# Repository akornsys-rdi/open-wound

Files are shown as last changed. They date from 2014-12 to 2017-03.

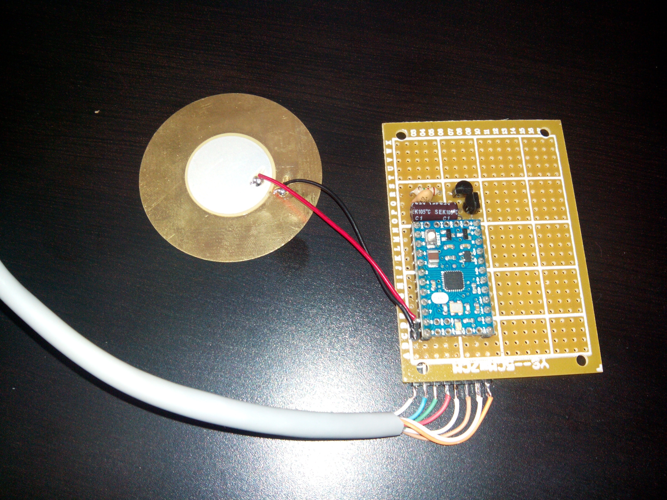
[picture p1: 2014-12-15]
img/photo001-slave-rc1.jpg

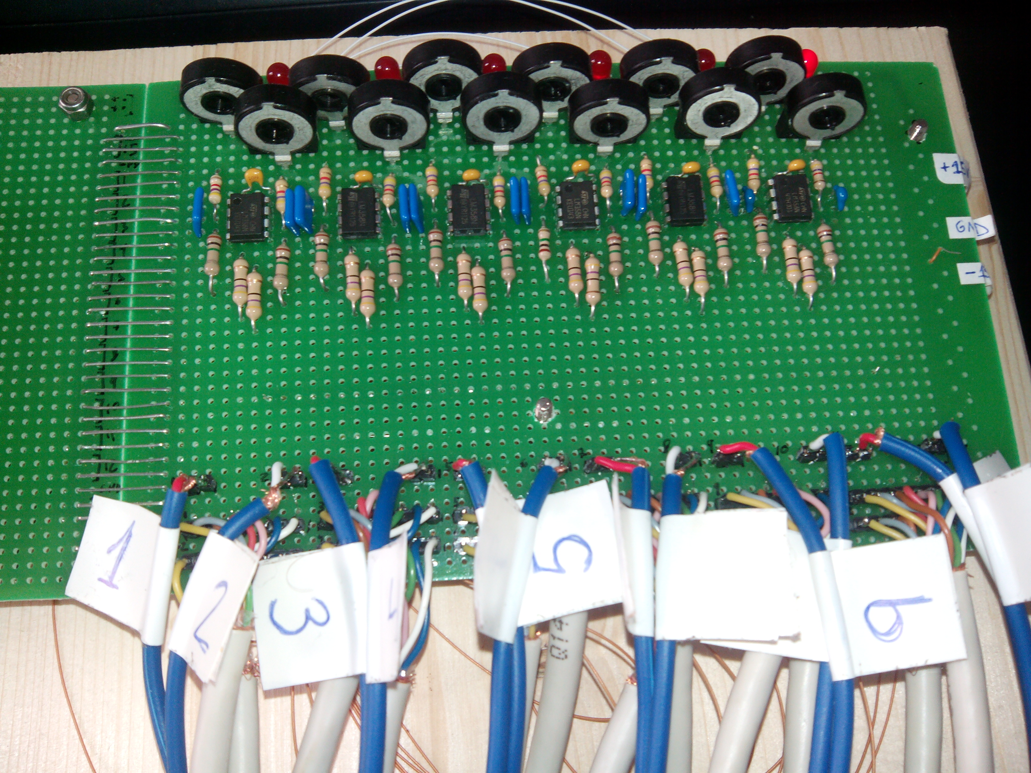
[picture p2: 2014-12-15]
img/photo003-master-rc1.jpg

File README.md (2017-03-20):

# open-wound #

                                                      _ 
         ___ _ __  ___ _ _   __ __ _____ _  _ _ _  __| |
        / _ \ '_ \/ -_) ' \  \ V  V / _ \ || | ' \/ _` |
        \___/ .__/\___|_||_|  \_/\_/\___/\_,_|_||_\__,_|
            |_|                                         

open wound, the system behind the [CUT artwork](http://arturomoyavillen.com/cut).

## ChangeLog  ##

-   Cambios generales:  
    *   Ahora open wound está bajo licencia GPLv3.  
    *   Open wound usa [versionamiento semántico](http://semver.org).  
-   Esclavos version 1.0.0:  
    *   Cambios menores en PCB.  
    *   El microcontrolador pasa a ser parte de la placa, no un módulo Arduino.  
    *   Los pines sin usar son salidas a nivel bajo no conectadas en lugar de entradas a masa.  
    *   Se añade un conector AVRISP de seis pines.  
    *   Se añade un conector de debug.  
    *   Placa diseñada en SMT..  
    *   Mejorado el método de conexión a la plancha sensora.  
    *   Ahora se usan conectores subminiatura con enclavamiento para su conexión.  
-   Maestro en versión 1.0.0-alpha:  
    *   El maestro ahora dispone de catorce canales para esclavos.  
    *   Se permiten cuatro canales para PIR compatibles con los esclavos.  
    *   Cambiado el CI amplificador.  
    *   Entrada de audio compacta medianteconector DA15F.  
    *   Buffer digital trigger-schmitt para acondicionar la señar de los esclavos.  
    *   Usa los propios LED del RJ45 para indicar conexión y dato entrante.  
    *   Ahora usa [FreeCanvas](https://github.com/synusia/freecanvas).

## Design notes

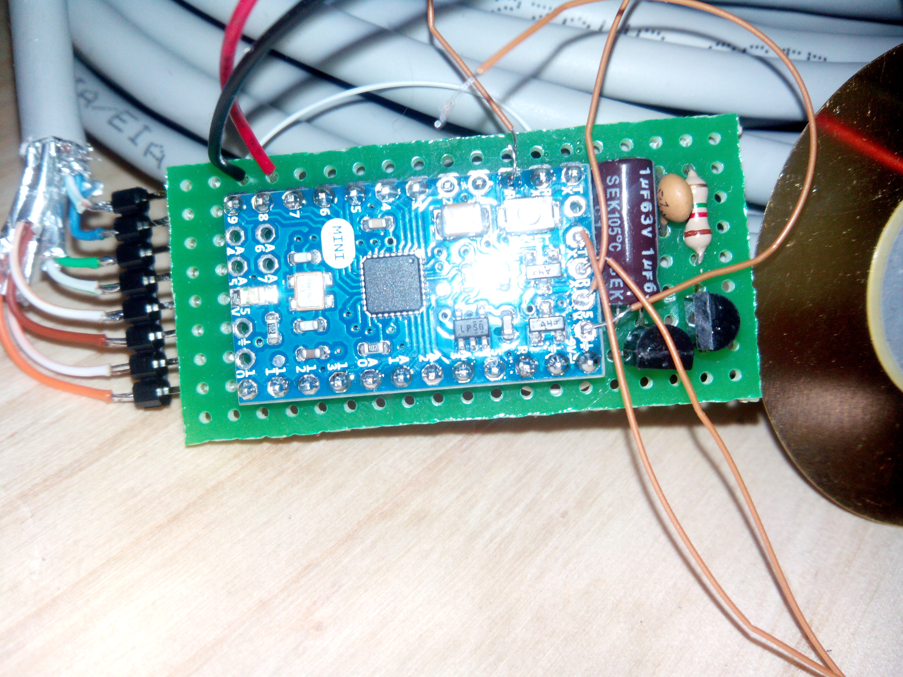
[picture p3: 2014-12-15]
img/photo004-slave-rc1.jpg

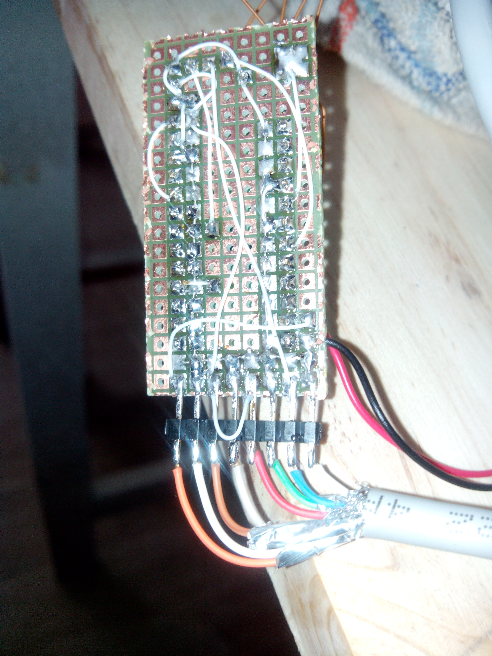
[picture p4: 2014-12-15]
img/photo005-slave-rc1.jpg

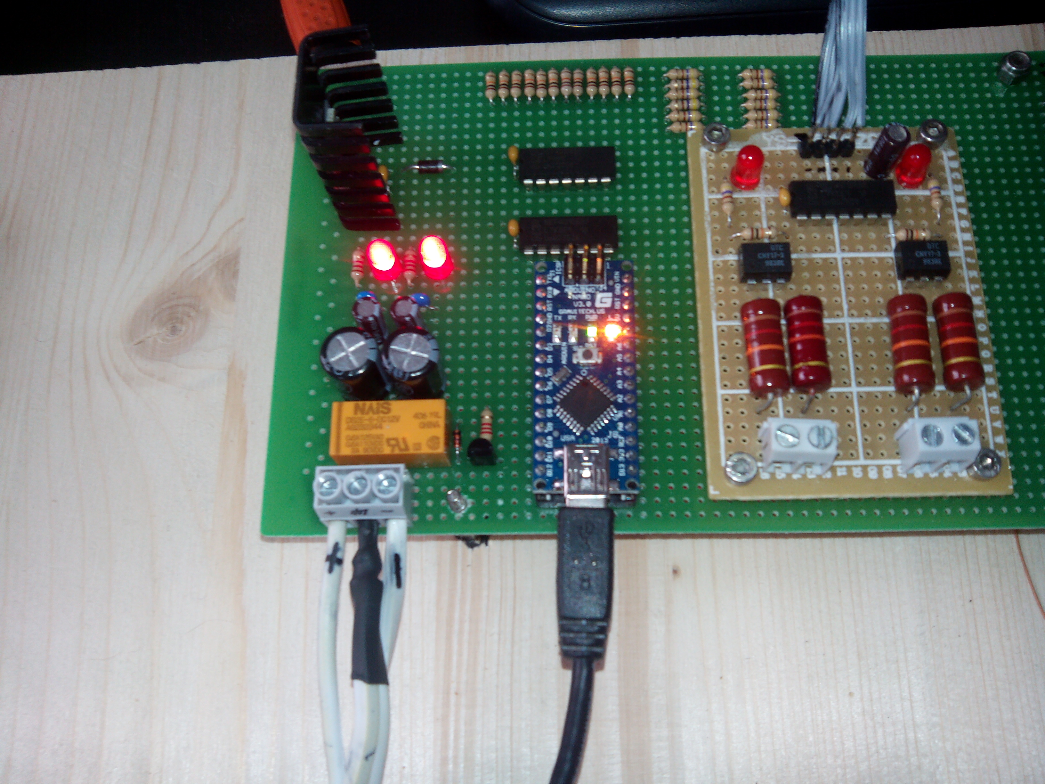
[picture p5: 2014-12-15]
img/photo002-master-rc1.jpg

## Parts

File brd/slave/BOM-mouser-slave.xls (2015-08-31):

open-wound:slave
Mouser REF | Fabr. N.º | Fabricante | Desc. | RoHS | Ciclo de vida | N.º Ref. del cliente | Ctd. pedido | Precio (EUR) | Ext.: (EUR)
598-AVE105M50B12T-F | AVE105M50B12T-F | Cornell Dubilier | Capacitadores electrolíticos de aluminio - SMD 1uF 50V 85C | Cumple RoHS |  |  | 1 | 0,314 € | 0,31 €
656-IL-Z-C3-A-15000 | IL-Z-C3-A-15000 | JAE Electronics | Alojamientos de cables y cabecera Socket Contact Crimp Tin 28-30AWG | Cumple RoHS |  |  | 16 | 0,053 € | 0,85 €
656-IL-Z-8S-S125C3 | IL-Z-8S-S125C3 | JAE Electronics | Alojamientos de cables y cabecera 8P Socket Housing 1.25mm Crimp | Cumple RoHS |  |  | 1 | 0,201 € | 0,20 €
656-IL-Z-6S-S125C3 | IL-Z-6S-S125C3 | JAE Electronics | Alojamientos de cables y cabecera 6P Socket Housing 1.25mm Crimp | Cumple RoHS |  |  | 1 | 0,146 € | 0,15 €
656-IL-Z-2S-S125C3 | IL-Z-2S-S125C3 | JAE Electronics | Alojamientos de cables y cabecera 2P Socket Housing 1.25mm Crimp | Cumple RoHS |  |  | 1 | 0,146 € | 0,15 €
656-IL-Z-8PL-SMTYE | IL-Z-8PL-SMTYE | JAE Electronics | Alojamientos de cables y cabecera 8P Pin Header 1.25mm R/A SMT | Cumple RoHS |  |  | 1 | 0,64 € | 0,64 €
656-IL-Z-6PL-SMTYE | IL-Z-6PL-SMTYE | JAE Electronics | Alojamientos de cables y cabecera 6P Pin Header 1.25mm R/A SMT | Cumple RoHS |  |  | 1 | 0,585 € | 0,59 €
656-IL-Z-2PL-SMTYE | IL-Z-2PL-SMTYE | JAE Electronics | Alojamientos de cables y cabecera 2P Pin Header 1.25mm R/A SMT | Cumple RoHS |  |  | 1 | 0,439 € | 0,44 €
71-CRCW0805-1.0M-E3 | CRCW08051M00FKEA | Vishay | Resistores de pel&iacute;cula gruesa - SMD 1/8watt 1Mohms 1% 100ppm | Conforme con RoHS por exención |  |  | 1 | 0,091 € | 0,09 €
603-SR0805JR-0710KL | SR0805JR-0710KL | Yageo | Resistores de pel&iacute;cula gruesa - SMD 10K ohm 5% 1/8W | Conforme con RoHS por exención |  |  | 1 | 0,256 € | 0,26 €
660-RK73B2ATTD222J | RK73B2ATTD222J | KOA Speer | Resistores de pel&iacute;cula gruesa - SMD 1/8watts 2.2Kohms 5% | Conforme con RoHS por exención |  |  | 1 | 0,101 € | 0,10 €
71-CRCW0603-10-E3 | CRCW060310R0FKEA | Vishay | Resistores de pel&iacute;cula gruesa - SMD 1/10watt 10ohms 1% | Conforme con RoHS por exención |  |  | 2 | 0,091 € | 0,18 €
583-BC847 | BC847-T | Rectron | Transistores bipolares - BJT Gen Pur Trans NPN,0.1A,45V | Cumple RoHS |  |  | 1 | 0,184 € | 0,18 €
77-VJ0603Y104JXJPBC | VJ0603Y104JXJPW1BC | Vishay | Condensadores de cerámica multicapa (MLCC- SMD/SMT) 0603 0.1uF 16volts X7R 5% | Cumple RoHS |  |  | 3 | 0,091 € | 0,27 €
77-VJ0603Y103KXAAC | VJ0603Y103KXAAC | Vishay | Condensadores de cerámica multicapa (MLCC- SMD/SMT) 0.01uF 50volts X7R 0.1 | Cumple RoHS |  |  | 1 | 0,118 € | 0,12 €
77-VJ0603A101JXACBC | VJ0603A101JXACW1BC | Vishay | Condensadores de cerámica multicapa (MLCC- SMD/SMT) 0603 100pF 50volts C0G 5% | Cumple RoHS |  |  | 1 | 0,054 € | 0,05 €
77-VJ0603A220JXACBC | VJ0603A220JXACW1BC | Vishay | Condensadores de cerámica multicapa (MLCC- SMD/SMT) 0603 22pF 50volts C0G 5% | Cumple RoHS |  |  | 2 | 0,054 € | 0,11 €
140-VE100M1HTR0505 | VE-100M1HTR-0505 | Lelon | Capacitadores electrolíticos de aluminio - SMD 50 Volts 10uF 20% 5x5.3 | Cumple RoHS |  |  | 1 | 0,205 € | 0,21 €
774-ATS16ASM-1 | ATS16ASM-1 | CTS | Cristales 16MHz 20pF 30ppm -20C 70C | Cumple RoHS |  |  | 1 | 0,348 € | 0,35 €
821-TS78L05ACY | TS78L05ACY | Taiwan Semiconductor | Reguladores de voltaje lineal 0.1 Amp 5.0 Volt 2% Fixed Positive | Conforme con RoHS por exención |  |  | 1 | 0,605 € | 0,61 €
556-ATMEGA328P-AU | ATMEGA328P-AU | Atmel | Microcontroladores (MCU) de 8 bits 32KB In-system Flash 20MHz 1.8V-5.5V | Cumple RoHS |  |  | 1 | 3,10 € | 3,10 €

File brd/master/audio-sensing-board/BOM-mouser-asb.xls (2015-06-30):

open-wound:master:asb
Mouser REF | Fabr. N.º | Fabricante | Desc. | RoHS | Ciclo de vida | N.º Ref. del cliente | Ctd. pedido | Precio (EUR) | Ext.: (EUR)
771-BC847C-T/R | BC847C,215 | NXP | Transistores bipolares - BJT NPN GP 100MA 45V | Cumple RoHS |  |  | 4 | 0,123 € | 0,49 €
667-ERJ-6GEYJ152V | ERJ-6GEYJ152V | Panasonic | Resistores de pel&iacute;cula gruesa - SMD 0805 1.5Kohms 5% Tol | Conforme con RoHS por exención |  |  | 4 | 0,081 € | 0,32 €
77-VJ0805Y103JXBAC | VJ0805Y103JXBAC | Vishay | Condensadores de cerámica multicapa (MLCC- SMD/SMT) .01UF 100V 5% | Cumple RoHS |  |  | 18 | 0,054 € | 0,97 €
595-CD40106BM96 | CD40106BM96 | Texas Instruments | Inversores Hex Schmitt Trigger | Cumple RoHS |  |  | 4 | 0,38 € | 1,52 €
667-ERJ-6ENF4700V | ERJ-6ENF4700V | Panasonic | Resistores de pel&iacute;cula gruesa - SMD 0805 470ohms 1% Tol | Conforme con RoHS por exención |  |  | 18 | 0,026 € | 0,47 €
667-ERJ-6GEYJ911V | ERJ-6GEYJ911V | Panasonic | Resistores de pel&iacute;cula gruesa - SMD 0805 910ohms 5% Tol | Conforme con RoHS por exención |  |  | 18 | 0,018 € | 0,32 €
523-RJHSE-3381 | RJHSE-3381 | Amphenol | Conectores modulares / conectores ethernet CAT 5 MODULAR JACK HIGH TEMP | Cumple RoHS |  |  | 18 | 1,65 € | 29,70 €
538-39880-0303 | 39880-0303 | Molex | Bloques terminales fijos 3 CKT TERM. BLOCK 5.08mm | Cumple RoHS |  |  | 2 | 0,615 € | 1,23 €
649-ID15S33E4GX00LF | ID15S33E4GX00LF | FCI | Conectores estándar D-sub DSUB 15 POSITION |  |  |  | 1 | 0,996 € | 1,00 €
652-TC33X-2-503E | TC33X-2-503E | Bourns | Resistencias ajustables - SMD 3MM 50KOHMS 25% 0.1WATT OPEN FRM | Conforme con RoHS por exención |  |  | 14 | 0,216 € | 3,02 €
71-CRCW0805-1.0M-E3 | CRCW08051M00FKEA | Vishay | Resistores de pel&iacute;cula gruesa - SMD 1/8watt 1Mohms 1% 100ppm | Conforme con RoHS por exención |  |  | 14 | 0,044 € | 0,62 €
667-ERJ-6ENF4701V | ERJ-6ENF4701V | Panasonic | Resistores de pel&iacute;cula gruesa - SMD 0805 4.7Kohms 1% Tol | Conforme con RoHS por exención |  |  | 32 | 0,024 € | 0,77 €
667-ERJ-6GEYJ470V | ERJ-6GEYJ470V | Panasonic | Resistores de pel&iacute;cula gruesa - SMD 0805 47ohms 5% Tol | Conforme con RoHS por exención |  |  | 14 | 0,016 € | 0,22 €
140-VE100M1HTR0505 | VE-100M1HTR-0505 | Lelon | Capacitadores electrolíticos de aluminio - SMD 50 Volts 10uF 20% 5x5.3 | Cumple RoHS |  |  | 3 | 0,205 € | 0,62 €
555-RVO-25V4.7-R | RVO-25V4R7MD55P2U-R2 | Elna | Capacitadores electrolíticos de aluminio - SMD 25V 4.7uF 20% | Cumple RoHS |  |  | 2 | 0,238 € | 0,48 €
77-VJ0805V104MXBPBC | VJ0805V104MXBPW1BC | Vishay | Condensadores de cerámica multicapa (MLCC- SMD/SMT) 0805 0.1uF 100volts Y5V 20% | Cumple RoHS |  |  | 8 | 0,054 € | 0,43 €
77-VJ0805V334ZXACBC | VJ0805V334ZXACW1BC | Vishay | Condensadores de cerámica multicapa (MLCC- SMD/SMT) 0805 0.33uF 50volts Y5V +80-20% | Cumple RoHS |  |  | 14 | 0,091 € | 1,27 €
595-LM324ADR | LM324ADR | Texas Instruments | Amplificadores operacionales - Op Amps Quad GP Op Amp | Cumple RoHS |  |  | 4 | 0,362 € | 1,45 €

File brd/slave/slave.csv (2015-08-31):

Source: | /home/kwendenarmo/git-repos/local/synusia/open-wound/brd/slave/slave.sch
Date: | lun 31 ago 2015 19:58:44 CEST
Tool: | Eeschema 0.201508110901+6083~28~ubuntu14.04.1-product
Generator: | /usr/share/doc/kicad/scripts/bom-in-python/bom_csv_grouped_by_value_with_fp.py
Component Count: | 23
Ref | Qnty | Value | Cmp name | Footprint | Description | Vendor
C1, | 1 | 10uF | CP_Small | Capacitors_SMD:c_elec_5x5.3 |  | 140-VE100M1HTR0505
C2, | 1 | 1uF | CP_Small | Capacitors_SMD:c_elec_4x5.3 |  | 598-AVE105M50B12T-F
C3, | 1 | 10nF | C_Small | Capacitors_SMD:C_0603_HandSoldering |  | 77-VJ0603Y103KXAAC
C4, C5, C7, | 3 | 100nF | C_Small | Capacitors_SMD:C_0603_HandSoldering |  | 77-VJ0603Y104JXJPBC
C6, C8, | 2 | 22pF | C_Small | Capacitors_SMD:C_0603_HandSoldering |  | 77-VJ0603A220JXACBC
C9, | 1 | 100pF | C_Small | Capacitors_SMD:C_0603_HandSoldering |  | 77-VJ0603A101JXACBC
P1, | 1 | AVRISP | CONN_02X03 | Pin_Headers:Pin_Header_Straight_2x03
P2, | 1 | IO | CONN_01X08 | asrdi-conn:IL-Z-8PL-SMTYE |  | 656-IL-Z-8PL-SMTYE
P3, | 1 | PIEZO | CONN_01X02 | asrdi-conn:IL-Z-2PL-SMTYE |  | 656-IL-Z-2PL-SMTYE
P4, | 1 | DEBUG | CONN_01X06 | asrdi-conn:IL-Z-6PL-SMTYE |  | 656-IL-Z-6PL-SMTYE
P5, | 1 | SENSE | CONN_01X01 | Wire_Pads:SolderWirePad_single_2mmDrill
Q1, | 1 | BC847 | BC849 | Housings_SOT-23_SOT-143_TSOT-6:SOT-23_Handsoldering |  | 583-BC847
R2, R1, | 2 | 10r | R | Resistors_SMD:R_0603_HandSoldering |  | 71-CRCW0603-10-E3
R3, | 1 | 10k | R | Resistors_SMD:R_0805_HandSoldering |  | 603-SR0805JR-0710KL
R4, | 1 | 1M | R | Resistors_SMD:R_0805_HandSoldering |  | 71-CRCW0805-1.0M-E3
R5, | 1 | 2k2 | R | Resistors_SMD:R_0805_HandSoldering |  | 660-RK73B2ATTD222J
U1, | 1 | LM78L05ACZ | LM78L05ACZ | Housings_SOT-89:SOT89-3_Housing_Handsoldering |  | 821-TS78L05ACY
U2, | 1 | ATMEGA328P-A | ATMEGA328P-A | Housings_QFP:TQFP-32_7x7mm_Pitch0.8mm |  | 556-ATMEGA328P-AU
X1, | 1 | 16MHz | Crystal | Crystals_Oscillators_SMD:Q_49U3HMS |  | 774-ATS16ASM-1

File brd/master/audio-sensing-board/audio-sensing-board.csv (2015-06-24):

Okness | Quantity | Value | Reference
v | 14x | R 47R | R17-R24;R37-R42
v | 18x | R 470R | R52-R57;R67-72;R78-R79;R87;R90;R95;R98
v | 18x | R 910R | R49-R51;R64-R66;R75-R77;R80-R84;R86;R89;R94;R97
v | 4x | R 1k5 | R85;R88;R93;R96
v | 32x | R 4k7 | R2;R4;R6;R8;R10;R12;R14;R16;R26;R28;R30;R32;R34;R36;R43-R48;R58-R63;R73-R74;R91-R92;R99;R100
v | 14x | R 1M | R1;R3;R5;R7;R9;R11;R13;R15;R25;R27;R29;R31;R33;R35
v | 14x | POT 50k | RV1-RV14
v | 18x | C 10nF MLCC | C22;C24-C26;C28-C30;C32-C37;C40-C42;C44-C45
v | 8x | C 100nF MLCC | C12-C13;C20-C21;C23;C27;C31;C43
v | 14x | C 330nF MLCC | C4-C11;C14-C19
v | 2x | C 4,7uF elect | C1-C2
v | 3x | C 10uF elect | C3;C38-C39
v | 4x | BC547 | Q1-Q4
v | 4x | LM324 | U1-U4
v | 4x | CD40106 | U5-U8
v | 1x | DB15F | J2
v | 18x | RJ45S | J3-J14;J17-J18;J21-J24
 | 3x | HEADER2x8 | J15-J16;J25
v | 2x | TERMBLOCK3 | J1;J19
 | 1x | PE | J20

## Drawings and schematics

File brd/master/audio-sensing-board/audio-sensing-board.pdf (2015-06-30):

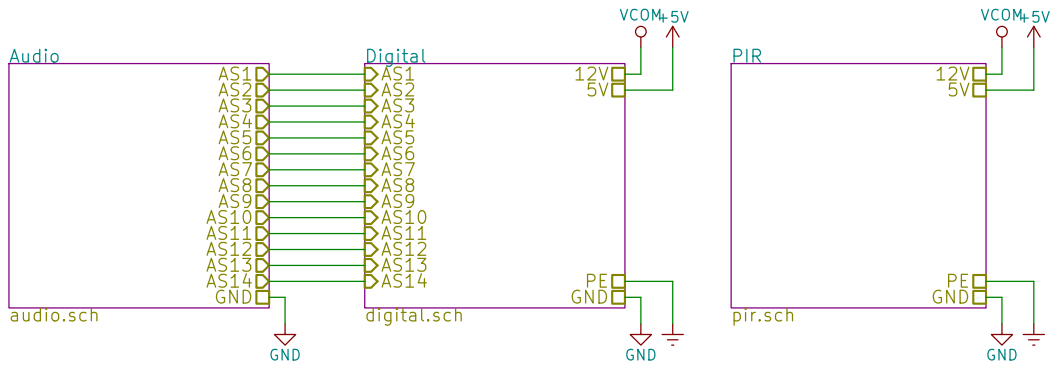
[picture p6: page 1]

File: audio-sensing-board.sch Sheet: / Synusia Under GPLv3 License Designed by kwendenarmo

Id: 1/4 Title: Open wound

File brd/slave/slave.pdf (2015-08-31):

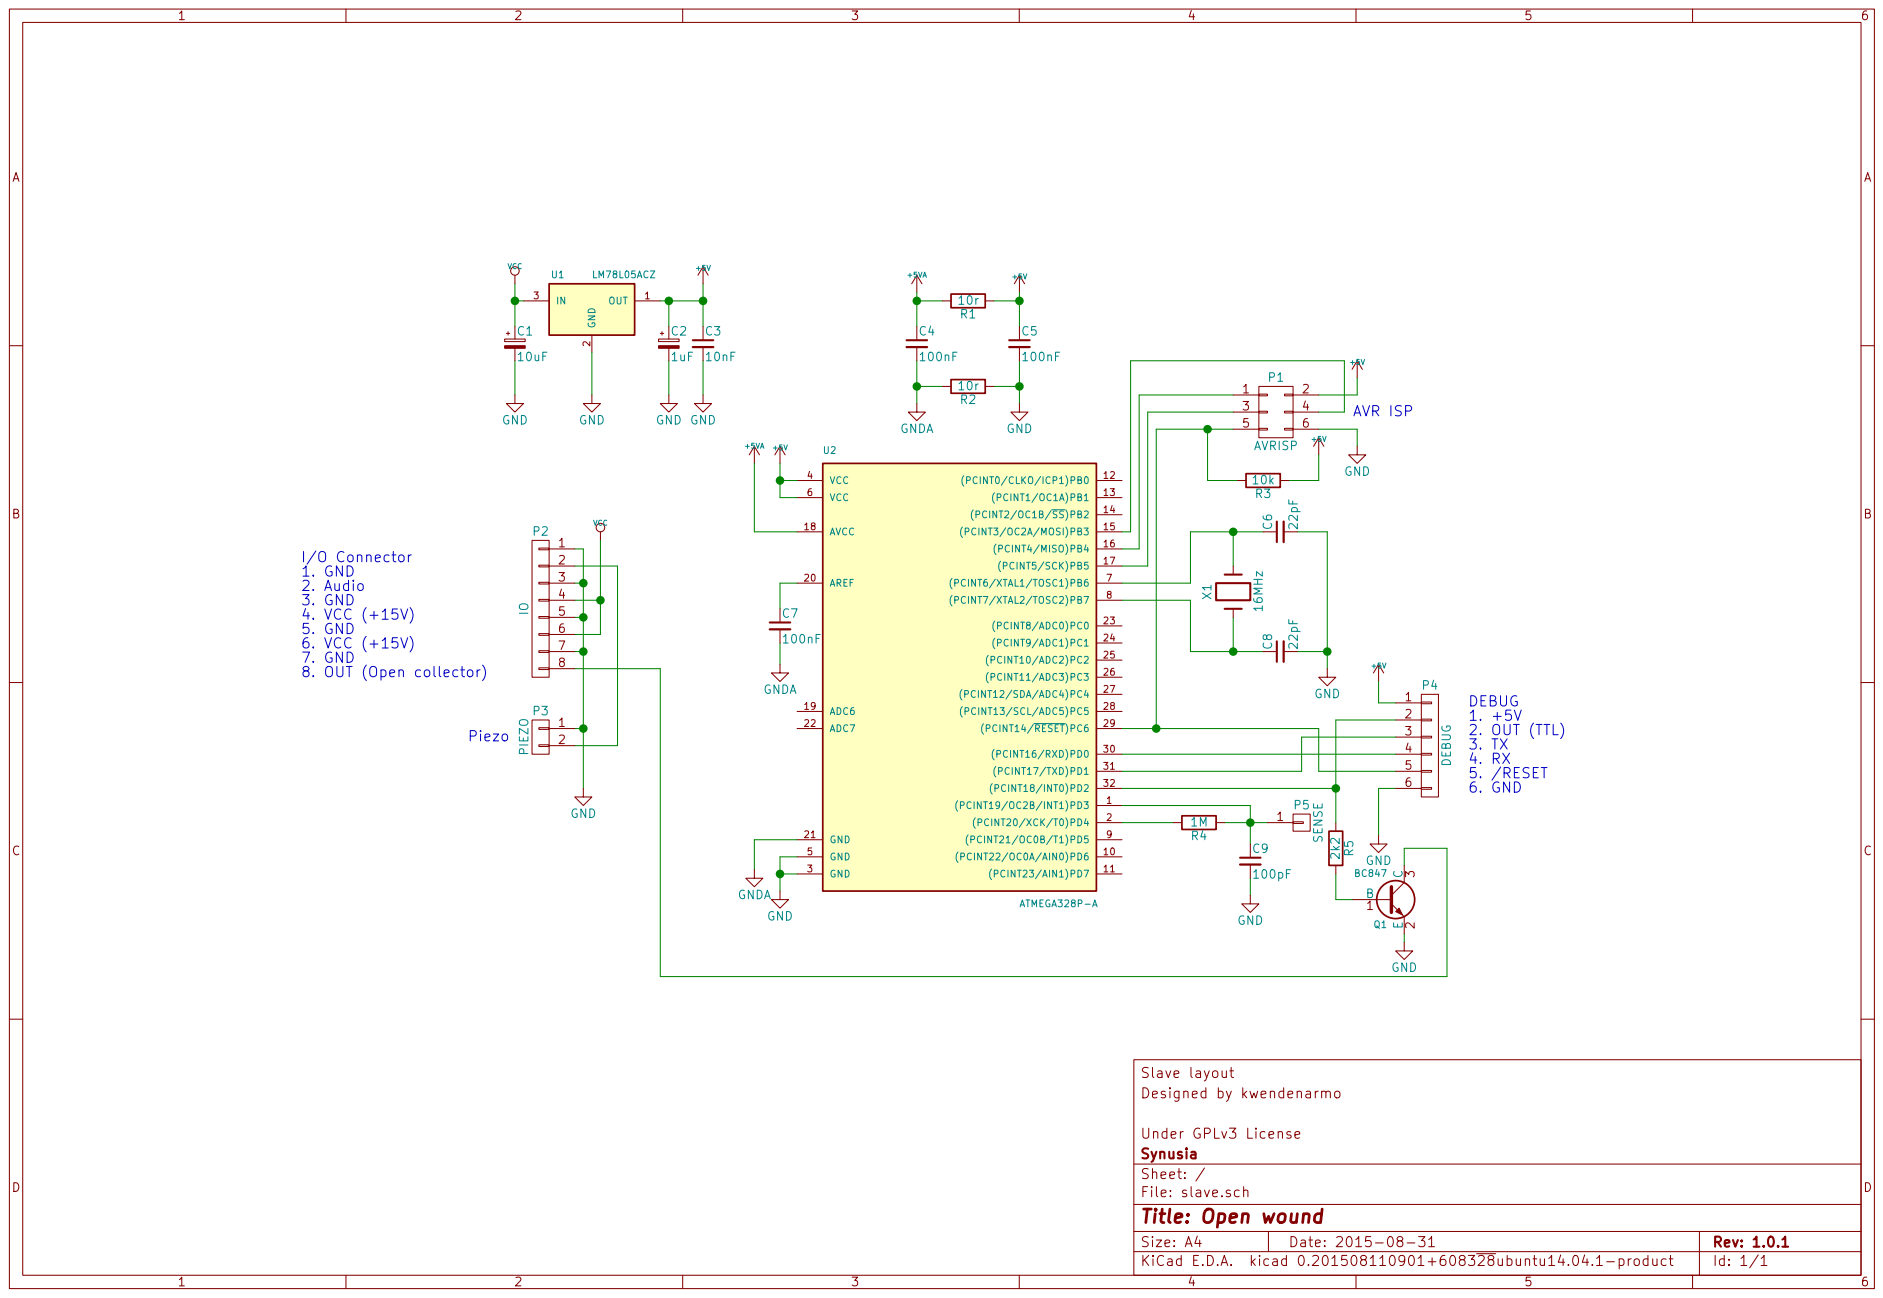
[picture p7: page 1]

Slave layout
File: slave.sch Sheet: / Synusia Under GPLv3 License Designed by kwendenarmo

Id: 1/1 Title: Open wound

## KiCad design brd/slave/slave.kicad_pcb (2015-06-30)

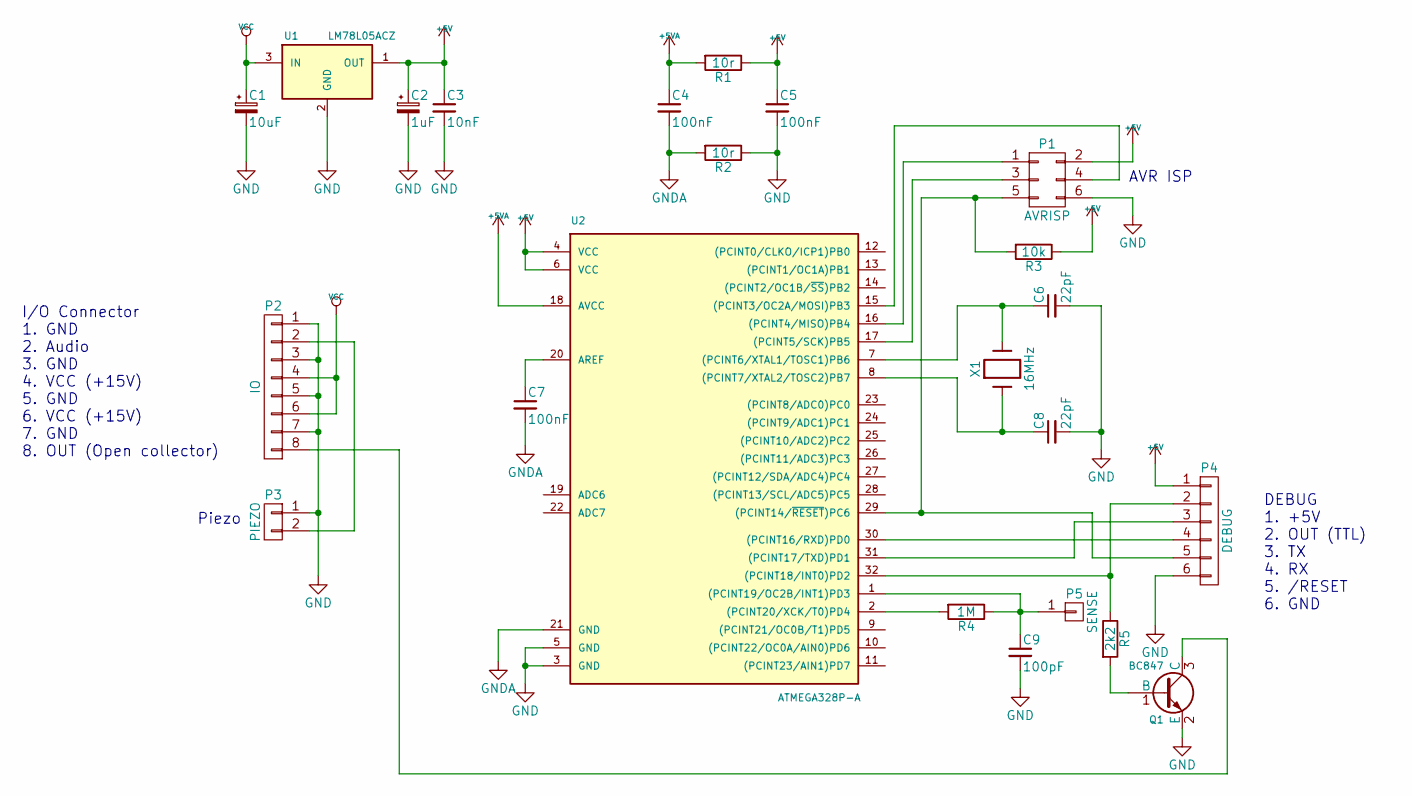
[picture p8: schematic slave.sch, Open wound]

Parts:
C1: 10uF; c_elec_5x5.3
C2: 1uF; c_elec_4x5.3
C3: 10nF; C_0603_HandSoldering
C4, C5, C7: 100nF; C_0603_HandSoldering
C6, C8: 22pF; C_0603_HandSoldering
C9: 100pF; C_0603_HandSoldering
P1: AVRISP; Pin_Header_Straight_2x03
P2: IO; IL-Z-8PL-SMTYE
P3: PIEZO; IL-Z-2PL-SMTYE
P4: DEBUG; IL-Z-6PL-SMTYE
P5: SENSE; SolderWirePad_single_2mmDrill
Q1: BC847; SOT-23_Handsoldering
R1, R2: 10r; R_0603_HandSoldering
R3: 10k; R_0805_HandSoldering
R4: 1M; R_0805_HandSoldering
R5: 2k2; R_0805_HandSoldering
U1: LM78L05ACZ; SOT89-3_Housing_Handsoldering
U2: ATMEGA328P-A; TQFP-32_7x7mm_Pitch0.8mm
X1: 16MHz; Q_49U3HMS

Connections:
+5V: C2.1, C3.1, C5.1, P1.2, P4.1, R1.1, R3.1, U1.1 (OUT), U2.4 (VCC), U2.6 (VCC)
+5VA: C4.1, R1.2, U2.18 (AVCC)
GND: C1.2, C2.2, C3.2, C5.2, C6.2, C8.2, C9.2, P1.6, P2.1, P2.3, P2.5, P2.7, P3.1, P4.6, Q1.2 (E), R2.1, U1.2 (GND), U2.3 (GND), U2.5 (GND)
GNDA: C4.2, C7.2, R2.2, U2.21 (GND)
unnamed: C6.1, U2.7 ((PCINT6/XTAL1/TOSC1)PB6), X1.2
unnamed: C7.1, U2.20 (AREF)
unnamed: C8.1, U2.8 ((PCINT7/XTAL2/TOSC2)PB7), X1.1
unnamed: C9.1, P5.1, R4.1, U2.1 ((PCINT19/OC2B/INT1)PD3)
unnamed: P1.1, U2.16 ((PCINT4/MISO)PB4)
unnamed: P1.3, U2.17 ((PCINT5/SCK)PB5)
unnamed: P1.4, U2.15 ((PCINT3/OC2A/MOSI)PB3)
unnamed: P1.5, P4.5, R3.2, U2.29 ((PCINT14/~RESET~)PC6)
unnamed: P2.2, P3.2
unnamed: P2.8, Q1.3 (C)
unnamed: P4.2, R5.1, U2.32 ((PCINT18/INT0)PD2)
unnamed: P4.3, U2.31 ((PCINT17/TXD)PD1)
unnamed: P4.4, U2.30 ((PCINT16/RXD)PD0)
unnamed: Q1.1 (B), R5.2
unnamed: R4.2, U2.2 ((PCINT20/XCK/T0)PD4)
VCC: C1.1, P2.4, P2.6, U1.3 (IN)

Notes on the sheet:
Piezo
AVR ISP
DEBUG 1. +5V 2. OUT (TTL) 3. TX 4. RX 5. /RESET 6. GND
I/O Connector 1. GND 2. Audio 3. GND 4. VCC (+15V) 5. GND 6. VCC (+15V) 7. GND 8. OUT (Open collector)

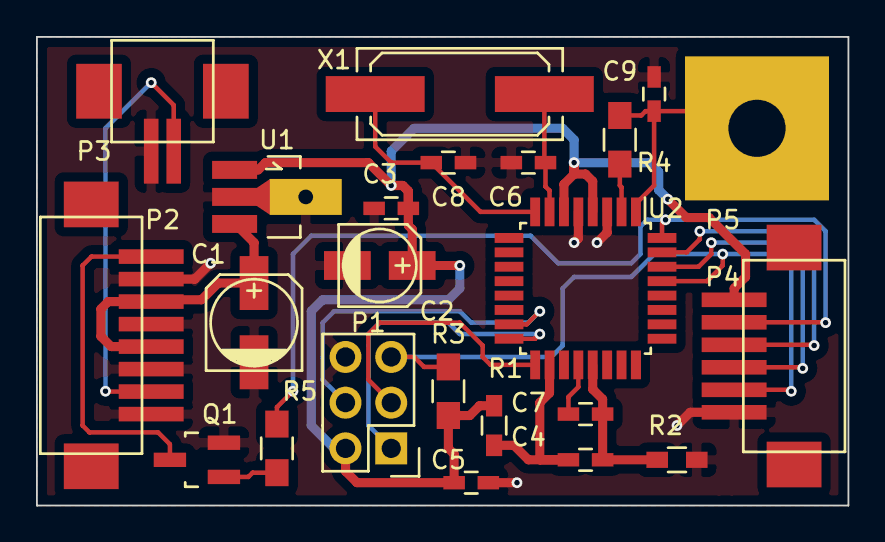
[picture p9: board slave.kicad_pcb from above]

Board: 2 copper layers, 45.1 x 26.0 mm, 23 parts (0 on the bottom side), 20 nets.

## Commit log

2014-07-30 new rc2 version
    [blade-mini.sch, slave.kicad_pcb, slave.sch]
2014-08-01 master rc2 version
    [audio.sch, blade-master.sch, digital.sch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]
2014-12-15 layout rework & gerber generation for slave pcb
    [slave-B_Cu.gbr, slave-B_Mask.gbr, slave-B_SilkS.gbr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]
2015-05-24 slave version rc3
    [audio.sch, digital.sch, main.sch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]
2015-06-24 master rc3 w/ freecanvas alpha
    [audio-sensing-board.csv, audio-sensing-board.sch, audio.sch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]
2015-06-30 versión 1.0.0
    [master.sch, power-supply.csv, power-supply.sch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]
2015-06-30 corregido descripción en archivos del maestro
    [audio-sensing-board.sch, audio.sch, digital.sch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]
2015-06-30 añadidos BOM de mouser
    [BOM-mouser-asb.xls, BOM-mouser-slave.xls]
2015-08-31 versión slave 1.0.1 añadido BOM y referencias a esquemático
    [BOM-mouser-slave.xls, slave.csv, slave.sch]

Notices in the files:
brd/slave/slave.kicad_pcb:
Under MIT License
